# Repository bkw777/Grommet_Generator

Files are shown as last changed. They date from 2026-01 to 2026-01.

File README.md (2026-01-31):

# 2025 4Runner glove box latch grommet

Parametric latch grommet generator.

The default values generate a gommet for the latches for the glove box door on a 6th gen (2025+) Toyota 4Runner.  
In the default case for the 6th gen 4Runner, install with the thick wall towards the rear of the vehicle.

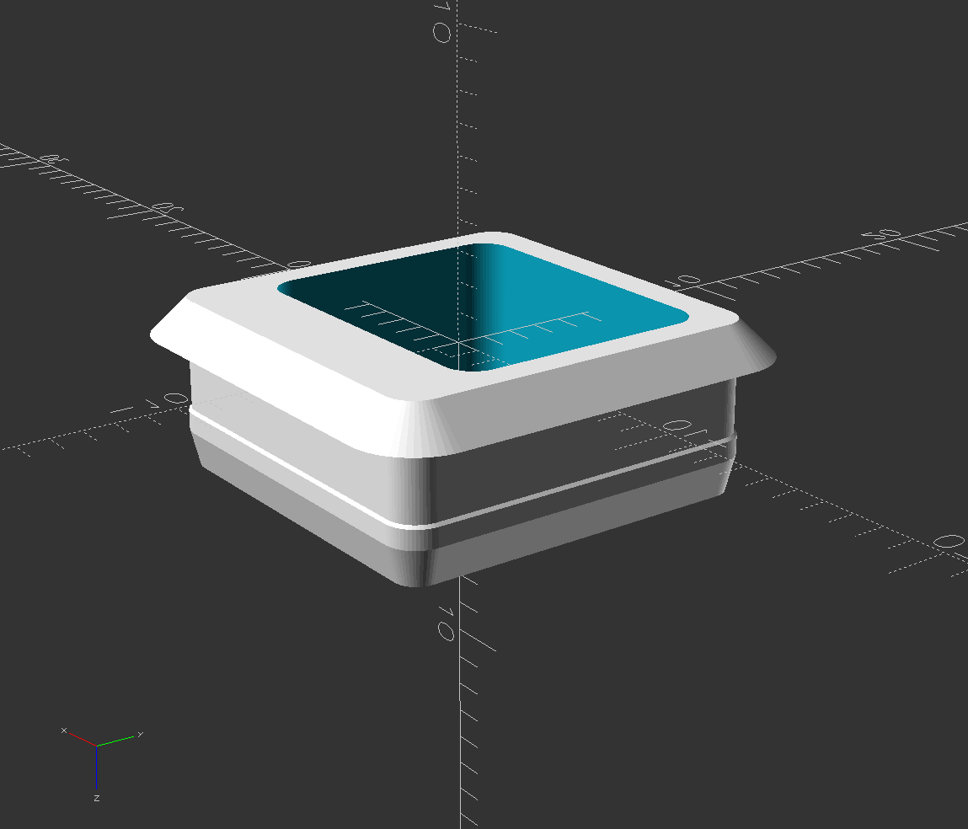
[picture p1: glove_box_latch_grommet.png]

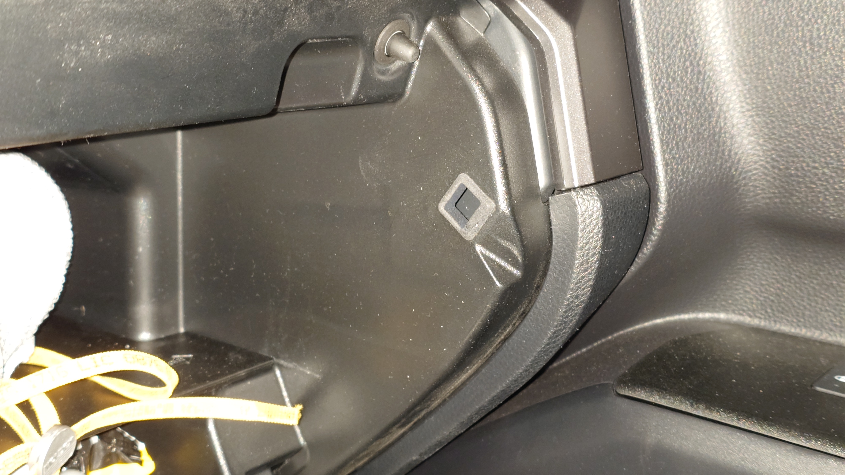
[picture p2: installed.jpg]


[Buy from JawsTec](https://shop.jawstec.com/3d-printed-2025-4runner-glove-box-latch-grommet_p640.php)  
(Select: MJF Nylon (not glass filled), Black color, No polish, Quantity 2 per vehicle.)

[STL for printing](out)

## Customization
(all values in mm)

Open the scad file in openscad, and enable the customizer panel.

If you have some other vehicle besides a 2025 4Runner and the holes in the glove box are not 13x13, just measure your holes and edit  
`glove_box_hole_vertical`  
`glove_box_hole_horizontal`

If the default model is too tight, and flipping the other way is too loose, reduce `pawl_hole_horizontal_offset`.

If the hole in the middle is too wide or too narrow for your pawl, edt `pawl_horizontal`.  
This should be the thickness of the pawl from front to back.

For `glove_box_hole_*` and `pawl_horizontal`, just use the actual dimensions of the features on the vehicle, don't try to adjust for clearance, there are other seperate values that add clearances.

### Fancy Compliant SLS MJF
If you want there is also a fancy version with a larger retainer bump and slots cut in the corners to make the retainer more compliant.  
This version is probably not good to print at home on a normal FDM printer because the tabs will likely break off.  
So this is really only for getting commercially printed using SLS or MJF.  
To generate or customize this version, select the "Fancy Compliant SLS MJF" saved config in the customizer panel.  
The interesting parameters for this version are:  
`retainer_slots_depth_percent` Anything greater than 0 enables the slots, and you want something between 50 to 100.  
And since the slots make the insert compliant, `retainer_oversize` can be increased to make a more solid snap.  

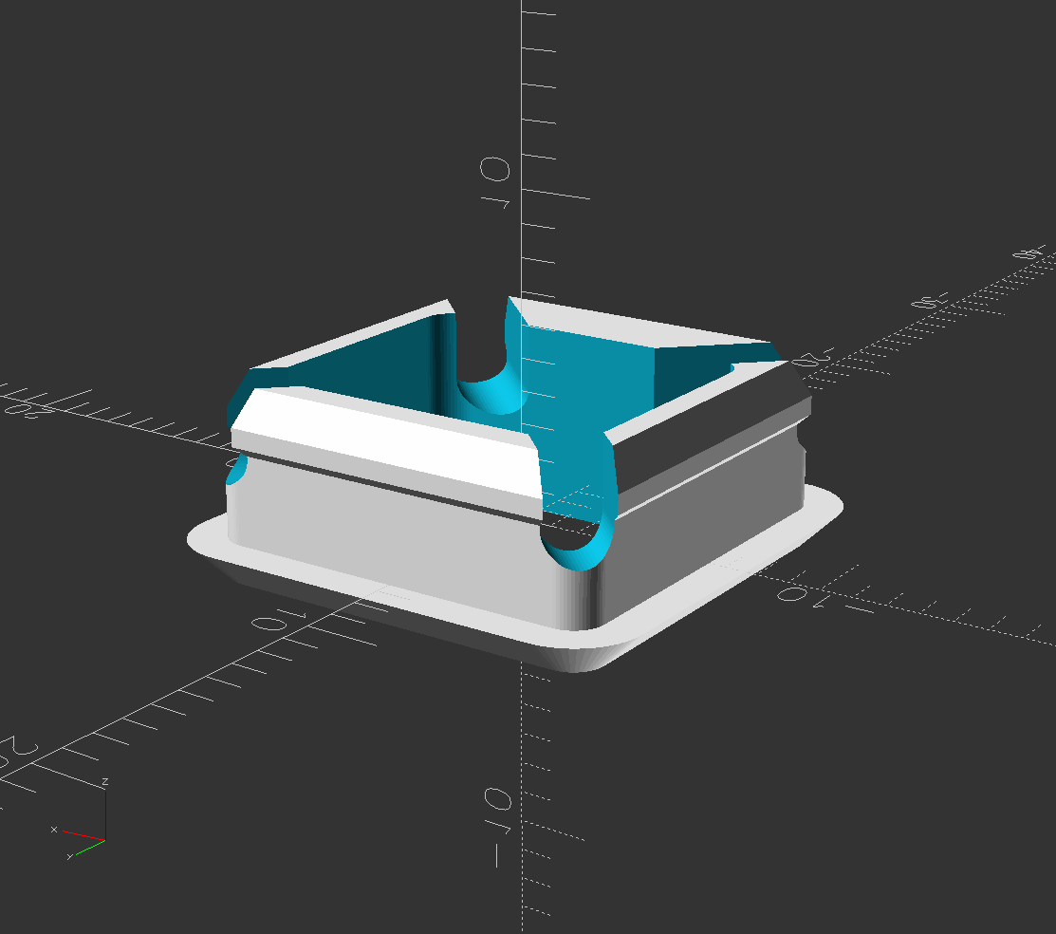
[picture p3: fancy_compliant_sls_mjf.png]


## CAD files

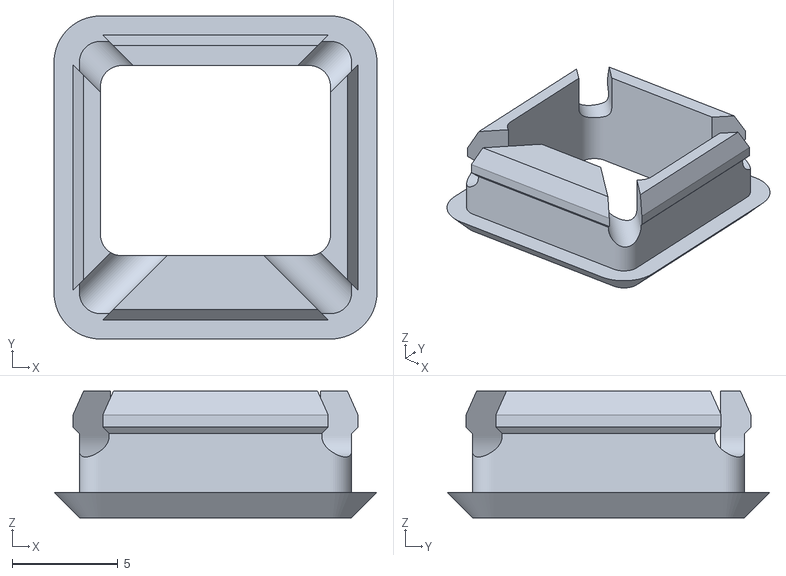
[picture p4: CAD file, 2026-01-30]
out/glove_box_latch_grommet_Fancy_Compliant_SLS_MJF.stl
15.3 x 15.3 x 6.00

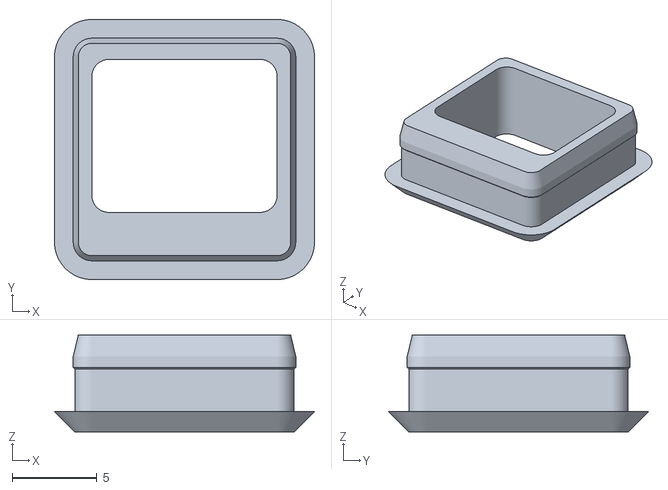
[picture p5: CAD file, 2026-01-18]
out/glove_box_latch_grommet.stl
15.3 x 15.3 x 5.70

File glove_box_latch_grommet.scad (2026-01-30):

// Toyota glove box latch grommet
// Default values are for 2025 4runner.

// For other years/models, use the customizer panel to change these values
// and save the config with a name with the model & year:
//   NOTES
//   glove_box_hole_vertical
//   glove_box_hole_horizontal
//   pawl_hole_horizontal_offset

// all values in mm
// the "// 0.1" comments control the customizer panel numerical fields

/* [Vehicle Site Reference Dimensions] */
NOTES = "Install with the thick wall towards the door.";
glove_box_wall_thickness = 2.8;    // 0.1
glove_box_hole_vertical = 13;      // 0.1
glove_box_hole_horizontal = 13;    // 0.1
pawl_horizontal = 8;               // 0.1
pawl_vertical = 8;                 // 0.1

/* [Parameters] */
fitment_clearance = 0.05;          // 0.01
corner_radius = 1;                 // 0.1

retainer_thickness = 2;            // 0.1
retainer_oversize = 0.1;           // 0.01
tip_undersize = 0.2;               // 0.1
retainer_ramp_percent = 66;        // [25:100]
retainer_slots_width = 2;          // 0.1
retainer_slots_depth_percent = 0;  // [0:100]

flange_thickness = 1.2;            // 0.1

pawl_clearance = 0.5;              // 0.1
pawl_hole_horizontal_offset = 0.8; // 0.1
pawl_hole_vertical_min_wall = 1;   // 0.1
pawl_hole_corner_radius = 1;       // 0.1

/* [Hidden] */

e = 0.1; // epsilon

// arc smoothness
//$fn = 32;
$fa = 6;
$fs = 0.1;

fc = fitment_clearance;
cr = corner_radius;
wall_h = glove_box_wall_thickness;
trunk_w = glove_box_hole_vertical - fc*2;
trunk_d = glove_box_hole_horizontal - fc*2;
ret_o = retainer_oversize;
ret_u = tip_undersize;
ret_w = trunk_w + ret_o*2;
ret_d = trunk_d + ret_o*2;
ret_h = retainer_thickness;
ramp_h = ret_h - ret_o - (((ret_h-ret_o)/100) * retainer_ramp_percent);
flange_h = flange_thickness;
flange_w = trunk_w + flange_h*2;
flange_d = trunk_d + flange_h*2;
hole_w = trunk_w - pawl_hole_vertical_min_wall*2;
hole_d = pawl_horizontal + pawl_clearance*2;
csw = (retainer_slots_width<0.8) ? 0 : retainer_slots_width ;
csl = (trunk_w+trunk_d) / 2;
csh =  wall_h + ret_h + e;
csz = wall_h - ((wall_h/100) * retainer_slots_depth_percent);
z_offset = $preview ? -flange_h : 0 ;

min_hole_w = pawl_vertical + pawl_clearance*2;
assert(hole_w >= min_hole_w);
// The hole width and depth come out almost the same, but they actually reference off of different things.
//
// The hole depth is the front-to-back size.
// It's the horizontal size of the pawl plus 2 times the pawl horizontal clearance.
// IE, it's as small as possible for the least door-rattle.
//
// The hole width is the top-to-bottom size.
// It's the vertical size of the grommet trunk minus 2 times the pawl hole minimum wall thickness.
// EI, it's as large as possible for the least chance of the side of the pawl hitting the side of the hole.
//
// In the case of the 2025 4Runner, the hole in the glove box and the shape of the pawl are both perfectly square,
// so the hole ends up coming out close to square too. But other vehicles have other dimensions where the distiction may have more effect.

module mirror_copy(v) {
 children();
 mirror(v) children();
}

// square cylinder
module sqyl (w=0,d=0,h=0,r=0,r1=-1,r2=-1) {
 ra = (r1<0) ? r : r1 ;
 rb = (r2<0) ? r : r2 ;
 R = max(ra,rb);
 hull()
   mirror_copy([0,1,0])
     mirror_copy([1,0,0])
       translate([w/2-R,d/2-R,0])
         cylinder(h=h,r1=ra,r2=rb,center=true);
}

module u (w,d,h) {
  r = w/2;
  translate([0,0,r/2])
    cube([w,d,h-r],center=true);
  translate([0,0,r-h/2])
    rotate([90,0,0])
      cylinder(h=d,r=r,center=true);
}

module grommet() {
  difference() {
    union() {

      // flange
      translate([0,0,flange_h/2])
        sqyl(w=flange_w,d=flange_d,h=flange_h,r1=cr,r2=cr+flange_h);

      // trunk
      ht = wall_h + e*2;
      translate([0,0,ht/2+flange_h-e])
        sqyl(w=trunk_w,d=trunk_d,h=ht,r=cr);

      // retainer
      ha = ret_o; // 45 deg
      hb = ret_h - ramp_h - ha;
      translate([0,0,flange_h+wall_h]) hull() {
        tw = trunk_w+ret_o*2;
        td = trunk_d+ret_o*2;
        translate([0,0,ha/2])
          sqyl(w=tw,d=td,h=ha,r1=cr,r2=cr+ret_o);
        translate([0,0,ret_h-hb/2])
          sqyl(w=tw,d=td,h=hb,r1=cr+ret_o,r2=cr-ret_u);
      }
    }

    // hole
    hh = flange_h + wall_h + ret_h + e*2;
    translate([0,pawl_hole_horizontal_offset,hh/2-e])
      sqyl(w=hole_w,d=hole_d,h=hh,r=pawl_hole_corner_radius);

    // compliant slots
    if (csw&&retainer_slots_depth_percent)
      translate([0,0,csh/2+flange_h+csz])
        mirror_copy([0,1,0])
          mirror_copy([1,0,0])
            translate([trunk_w/2,trunk_d/2,0])
              rotate([0,0,-45])
                u(w=csw,d=csl,h=csh);
  }
}

translate([0,0,z_offset]) grommet();

echo ();
echo ("****************************************");
echo ();
echo (NOTES);
echo ();
echo ("****************************************");
echo ();

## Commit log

2026-01-15 readme and refactor pawl hole vertical
    [glove_box_latch_grommet.scad]
2026-01-16 refactor without handy.scad, wall thickness 2.5
    [glove_box_latch_grommet.scad, glove_box_latch_grommet.stl]
2026-01-18 fancy compliant option
    [glove_box_latch_grommet.scad, glove_box_latch_grommet.stl, glove_box_latch_grommet_Fancy_Compliant_SLS_MJF.stl]
2026-01-30 deeper insert, compliant slots & retainers
    [glove_box_latch_grommet.scad, glove_box_latch_grommet_Fancy_Compliant_SLS_MJF.stl]
